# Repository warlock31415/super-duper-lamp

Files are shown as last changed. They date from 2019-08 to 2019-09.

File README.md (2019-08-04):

# super-duper-lamp
This repo contains files for building a single direction traffic control unit using discrete logic. 

The circuit uses a 555 timer to generate a 1Hz signal which increments a BCD counter. The outputs from the counter are fed into logic gates
to ensure that the correct light is turned on. The green and red lights1 thus turn on for 6 seconds individually. And the yellow light turns 
on for 4 seconds.

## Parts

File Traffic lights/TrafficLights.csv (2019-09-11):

Qty | Value | Device | Package | Parts | Description | CUI_PURCHASE_URL | DESCRIPTION | DIGI-KEY_PART_NUMBER | DIGI-KEY_PURCHASE_URL | MANUFACTURER | MANUFACTURER_PART_NUMBER | MF | MP | MPN | OC_FARNELL | OC_NEWARK | PACKAGE | POPULARITY | SPICEPREFIX | STANDARD | VALUE | VENDOR
3 | 1.33k | R-US_R1206 | R1206 | R4, R5, R6 | RESISTOR, American symbol |  |  |  |  |  |  |  |  |  |  |  |  | 19 | R
2 | 10k | R-US_0207/2V | 0207/2V | R11, R12 | RESISTOR, American symbol |  |  |  |  |  |  |  |  |  |  |  |  | 0 | R
3 | 10k | R-US_R1206 | R1206 | R1, R2, R13 | RESISTOR, American symbol |  |  |  |  |  |  |  |  |  |  |  |  | 19 | R
2 | 10uF | C-USC1206 | C1206 | C2, C3 | CAPACITOR, American symbol |  |  |  |  |  |  |  |  |  |  |  |  |  | C
5 | 1k | R-US_R1206 | R1206 | R3, R7, R8, R9, R10 | RESISTOR, American symbol |  |  |  |  |  |  |  |  |  |  |  |  | 19 | R
1 | 47uF | C-USC1206 | C1206 | C1 | CAPACITOR, American symbol |  |  |  |  |  |  |  |  |  |  |  |  |  | C
1 | CD4071BM96D14-M | CD4073BM96D14-M | D14-M | U6 |  |  |  |  |  |  | CD4073BM96 |  |  |  |  |  |  |  |  |  |  | Texas Instruments
1 | CD4073BM96D14-M | CD4073BM96D14-M | D14-M | U5 |  |  |  |  |  |  | CD4073BM96 |  |  |  |  |  |  |  |  |  |  | Texas Instruments
1 | CD4518BE | CD4518BE | N16 | U3 |  |  |  |  |  |  | CD4518BE |  |  |  |  |  |  |  |  |  |  | Texas Instruments
3 | CPC1970 | CPC1972 | 6-DIP | IC1, IC2, IC3 | Solid State Relay SPST-NO (1 Form A) 6-DIP |  |  |  |  |  | CPC1972G |  |  |  |  |  |  |  |  |  | CPC1970
1 | HEF4049B | HEF4049B | SO16 | IC5
1 | MC14081BDR2GSOIC-14_NB-M | MC14081BDR2GSOIC-14_NB-M | SOIC-14_NB-M | U4 |  |  |  |  |  |  | MC14081BDR2G |  |  |  |  |  |  |  |  |  |  | ON Semiconductor
1 | NE555 | NE555 | DIL-08 | IC4 | General purpose bipolar Timer |  |  |  |  |  |  | Arrow Electronics |  | NE555N | 1467742 | 89K1486
1 | PJ-037A | PJ-037A | CUI_PJ-037A | J2 | 2.0 mm Center Pin, 2.5 A, Right Angle, Through Hole, Dc Power Jack Connector | https://www.cui.com/product/interconnect/connectors/dc-power-connectors/jacks/pj-037a | 2.0 x 6.5 mm, 2.5 A, Horizontal, Through Hole, Dc Power Jack Connector | CP-037A-ND | https://www.digikey.com/product-detail/en/cui-inc/PJ-037A/CP-037A-ND/1644545 |  |  | CUI Inc. | PJ-037A |  |  |  | None
2 | SQ1922AEEH | SQ1922AEEH | SOT-363 | U1, U2 | Mosfet Array 2 N-Channel (Dual) 20V 850mA (Tc) 1.5W (Tc) Surface Mount SC-70-6 |  |  |  |  |  | SQ1922AEEH-T1_GE3
1 | TB002-500-04BE | TB002-500-04BE | CUI_TB002-500-04BE | J1 |  |  |  |  |  | CUI |  |  |  |  |  |  |  |  |  | Manufacturer Recommendations

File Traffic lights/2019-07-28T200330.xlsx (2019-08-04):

Index | Quantity | Part Number | Manufacturer Part Number | Description | Customer Reference | Available | Backorder | Unit Price | Extended Price USD
1 | 5 | CLA224-ND | CPC1972G | SSR RELAY SPST-NO 250MA 0-800V |  | 5 | 0 | 0.98 | 4.90
2 | 2 | 296-2076-5-ND | CD4518BE | IC BCD UP COUNTER DUAL 16-DIP |  | 2 | 0 | 0.56 | 1.12
3 | 3 | 296-31519-1-ND | CD4073BM96 | IC GATE AND 3CH 3-INP 14SOIC |  | 3 | 0 | 0.42 | 1.26
4 | 4 | MC14081BDR2GOSCT-ND | MC14081BDR2G | IC GATE AND 4CH 2-INP 14SOIC |  | 4 | 0 | 0.43 | 1.72
5 | 5 | 1727-6409-1-ND | HEF4049BT,653 | IC INVERTER 6CH 6-INP 16SO |  | 5 | 0 | 0.4 | 2.00
6 | 6 | 296-25953-1-ND | CD4071BM96 | IC GATE OR 4CH 2-INP 14SOIC |  | 6 | 0 | 0.42 | 2.52
7 | 7 | SQ1922AEEH-T1_GE3CT-ND | SQ1922AEEH-T1_GE3 | MOSFET N-CH DUAL 20V .85A SOT-36 |  | 7 | 0 | 0.52 | 3.64
8 | 1 | 377-1887-ND | PN-1320-CMB | BOX PLSTC GRAY/CLR 2.52" X 2.28" |  | 1 | 0 | 7.4 | 7.40
9 | 10 | RMCF1206FT10K0CT-ND | RMCF1206FT10K0 | RES 10K OHM 1% 1/4W 1206 |  | 10 | 0 | 0.036 | 0.36
10 | 10 | RNCP1206FTD1K00CT-ND | RNCP1206FTD1K00 | RES 1K OHM 1% 1/2W 1206 |  | 10 | 0 | 0.093 | 0.93
11 | 10 | RNCP1206FTD1K50CT-ND | RNCP1206FTD1K50 | RES 1.5K OHM 1% 1/2W 1206 |  | 10 | 0 | 0.093 | 0.93
12 | 10 | 1276-1853-1-ND | CL31F106ZPHNNNE | CAP CER 10UF 10V Y5V 1206 |  | 10 | 0 | 0.132 | 1.32
13 | 10 | 1276-3064-1-ND | CL31A476MQHNNWE | CAP CER 47UF 6.3V X5R 1206 |  | 10 | 0 | 0.336 | 3.36

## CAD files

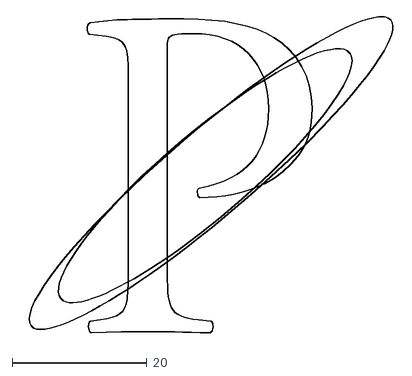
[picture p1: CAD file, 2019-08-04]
Traffic lights/drawing.dxf
56.3 x 47.4

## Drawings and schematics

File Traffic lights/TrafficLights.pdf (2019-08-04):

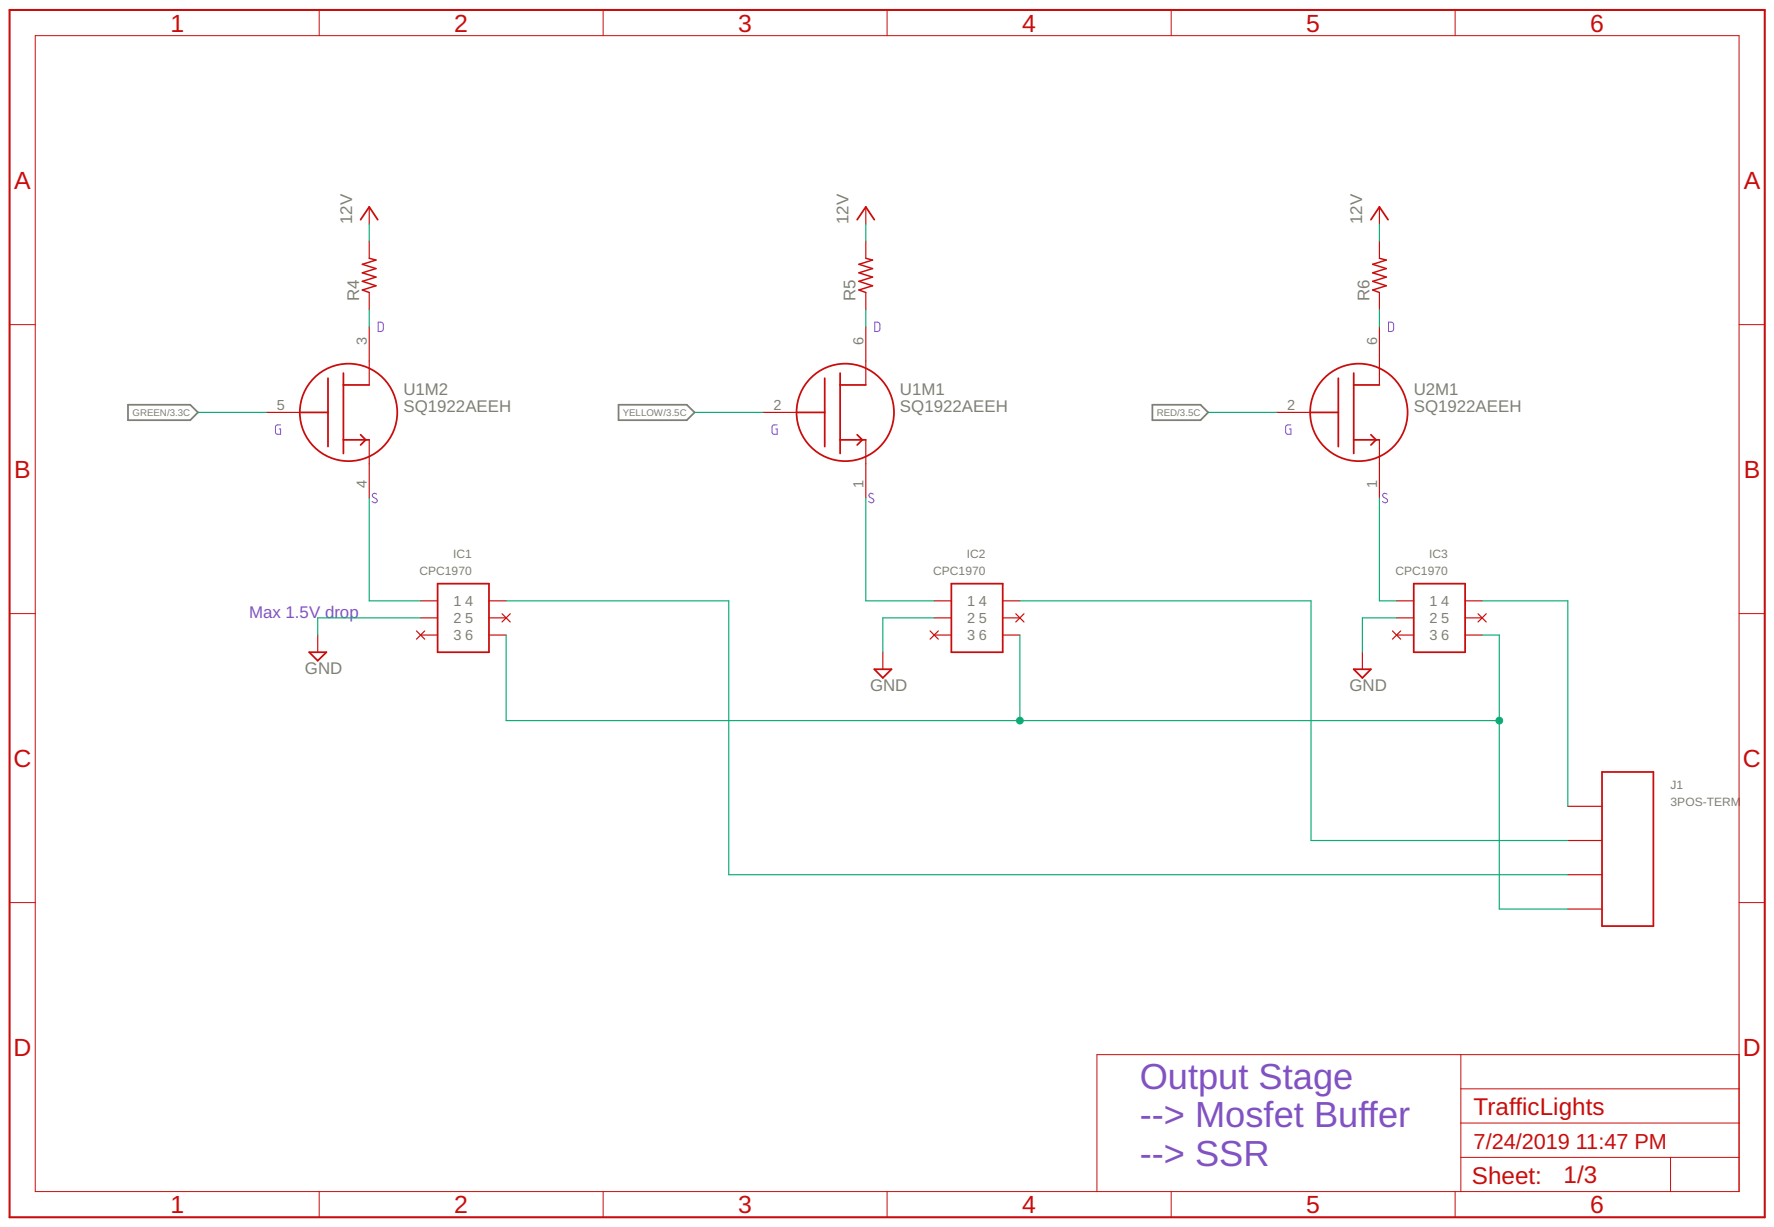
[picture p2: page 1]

Output Stage --> Mosfet Buffer --> SSR

Sheet: 1/3

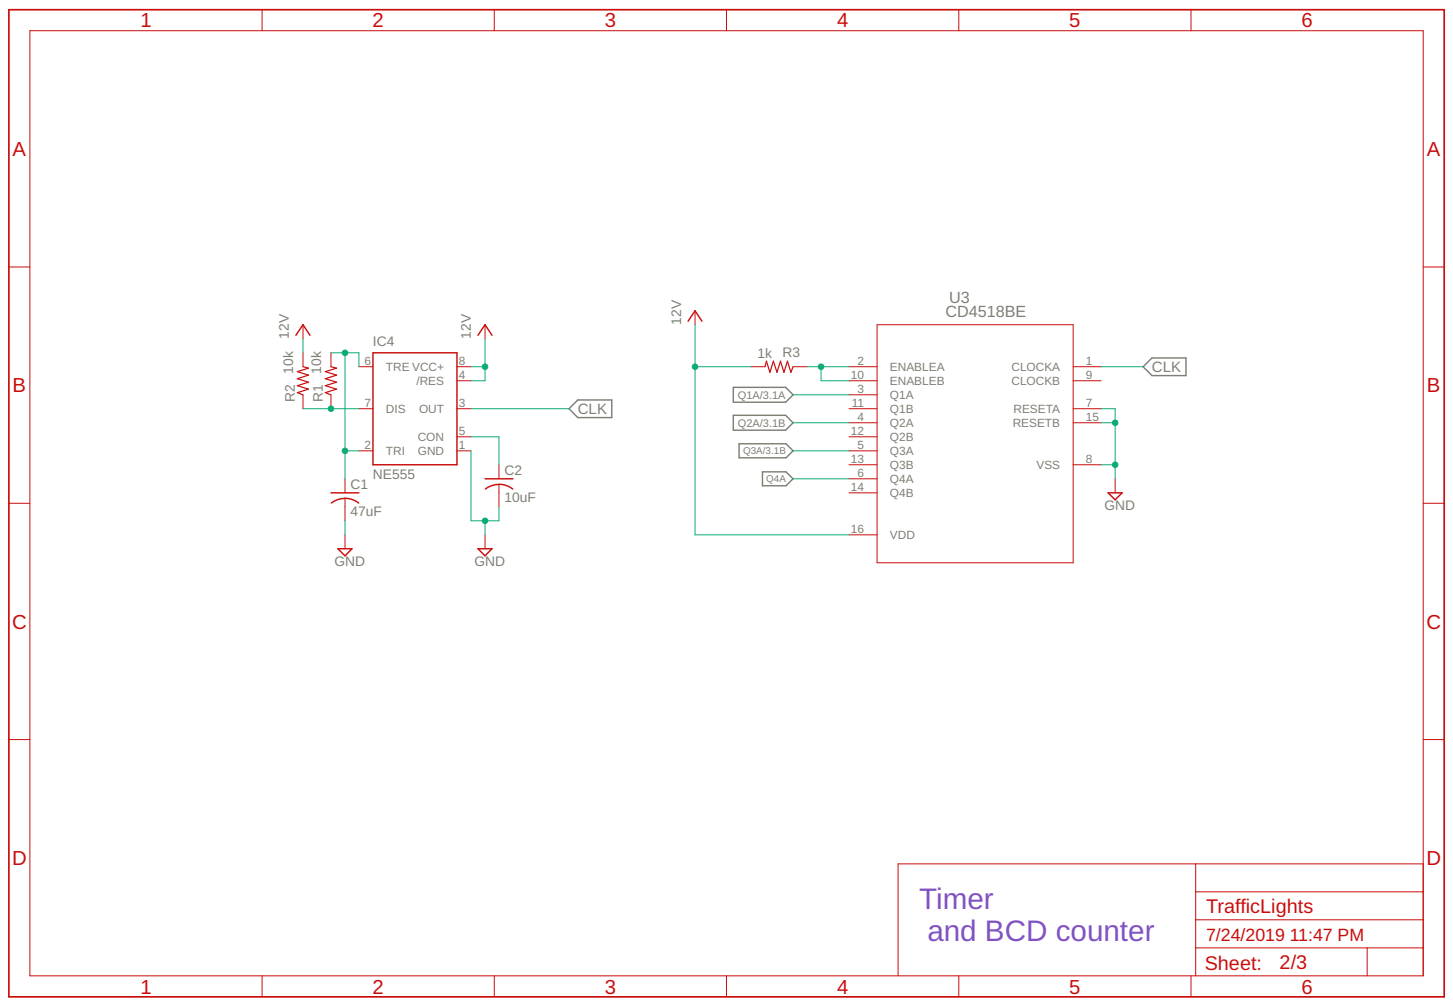
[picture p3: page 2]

Timer and BCD counter

Sheet: 2/3

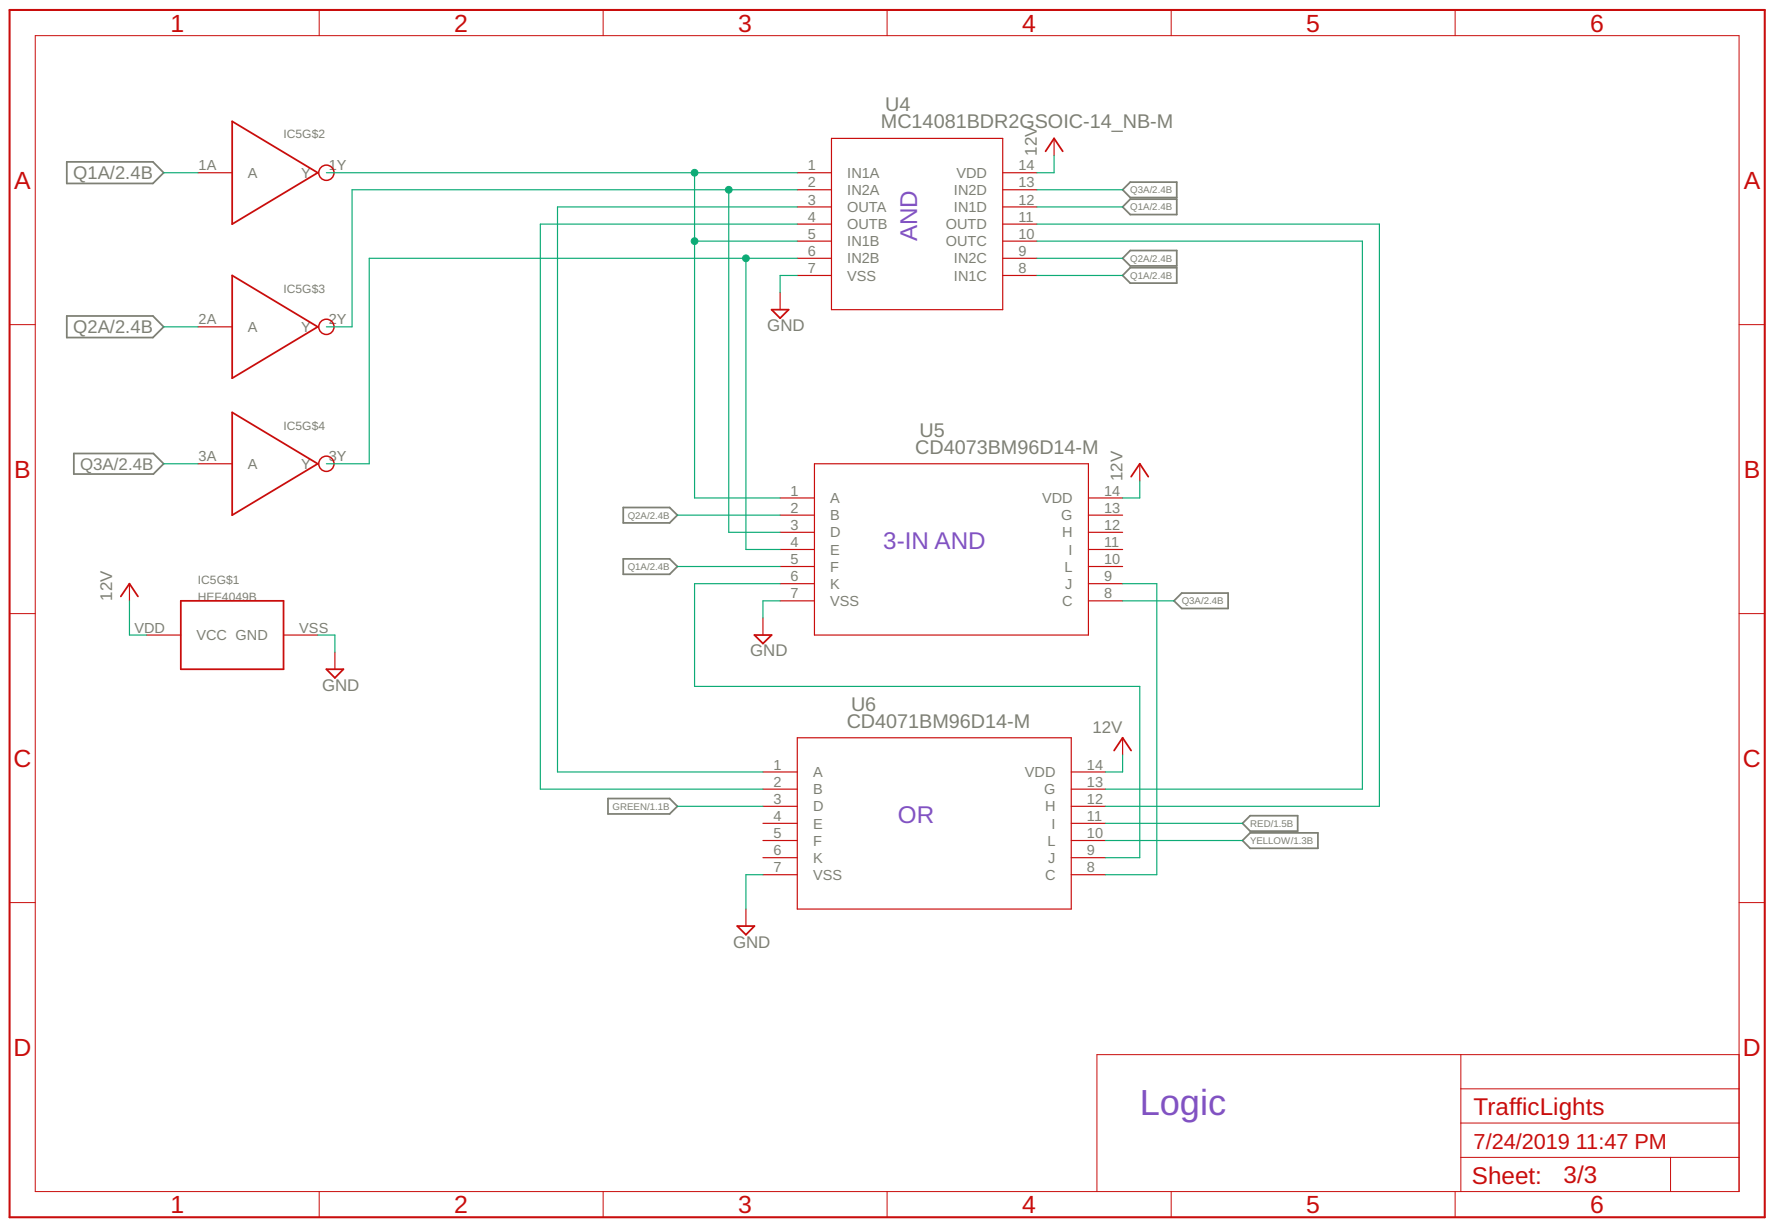
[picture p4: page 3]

Logic

Sheet: 3/3

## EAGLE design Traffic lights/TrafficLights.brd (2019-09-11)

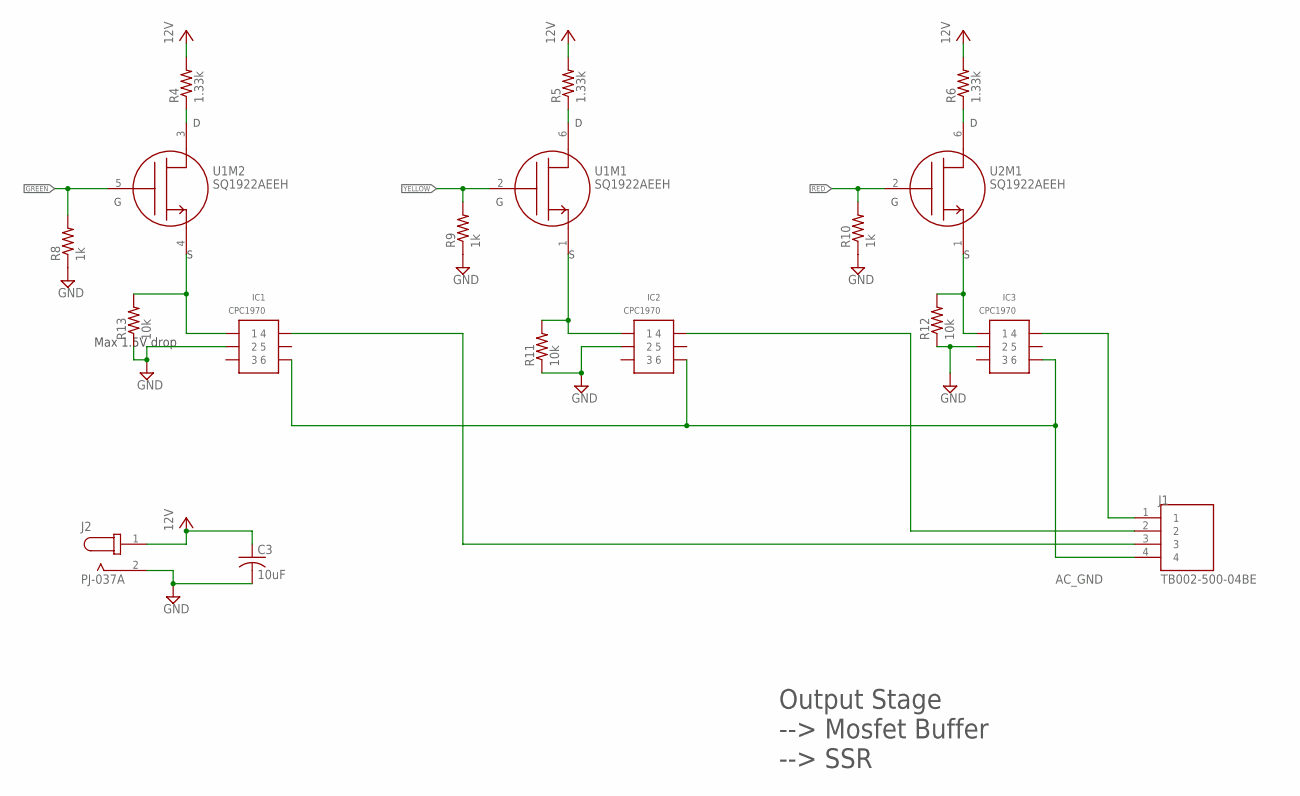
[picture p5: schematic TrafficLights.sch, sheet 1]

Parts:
C3: 10uF; C1206
IC1, IC2, IC3: CPC1970; 6-DIP
J1: TB002-500-04BE; CUI_TB002-500-04BE
J2: PJ-037A; CUI_PJ-037A
R4, R5, R6: 1.33k; R1206
R8, R9, R10: 1k; R1206
R11, R12: 10k; 0207/2V
R13: 10k; R1206
U1, U2: SQ1922AEEH; SOT-363

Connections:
AC_GND: IC1.P$6 (6), IC2.P$6 (6), IC3.P$6 (6), J1.4
GND: C3.2, IC1.P$2 (2), IC2.P$2 (2), IC3.P$2 (2), J2.2, R8.1, R9.1, R10.1, R11.1, R12.1, R13.1; also elsewhere on the board
GREEN: R8.2, U1.5 (G); also elsewhere on the board
unnamed: IC1.P$1 (1), R13.2, U1.4 (S)
unnamed: IC2.P$1 (1), R11.2, U1.1 (S)
unnamed: IC3.P$1 (1), R12.2, U2.1 (S)
unnamed: R4.1, U1.3 (D)
unnamed: R5.1, U1.6 (D)
unnamed: R6.1, U2.6 (D)
unnamed: IC2.P$4 (4), J1.2
unnamed: IC3.P$4 (4), J1.1
RED: R10.2, U2.2 (G); also elsewhere on the board
VAC: IC1.P$4 (4), J1.3
VCC: C3.1, J2.1, R4.2, R5.2, R6.2; also elsewhere on the board
YELLOW: R9.2, U1.2 (G); also elsewhere on the board

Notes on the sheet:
Max 1.5V drop
Output Stage --> Mosfet Buffer --> SSR

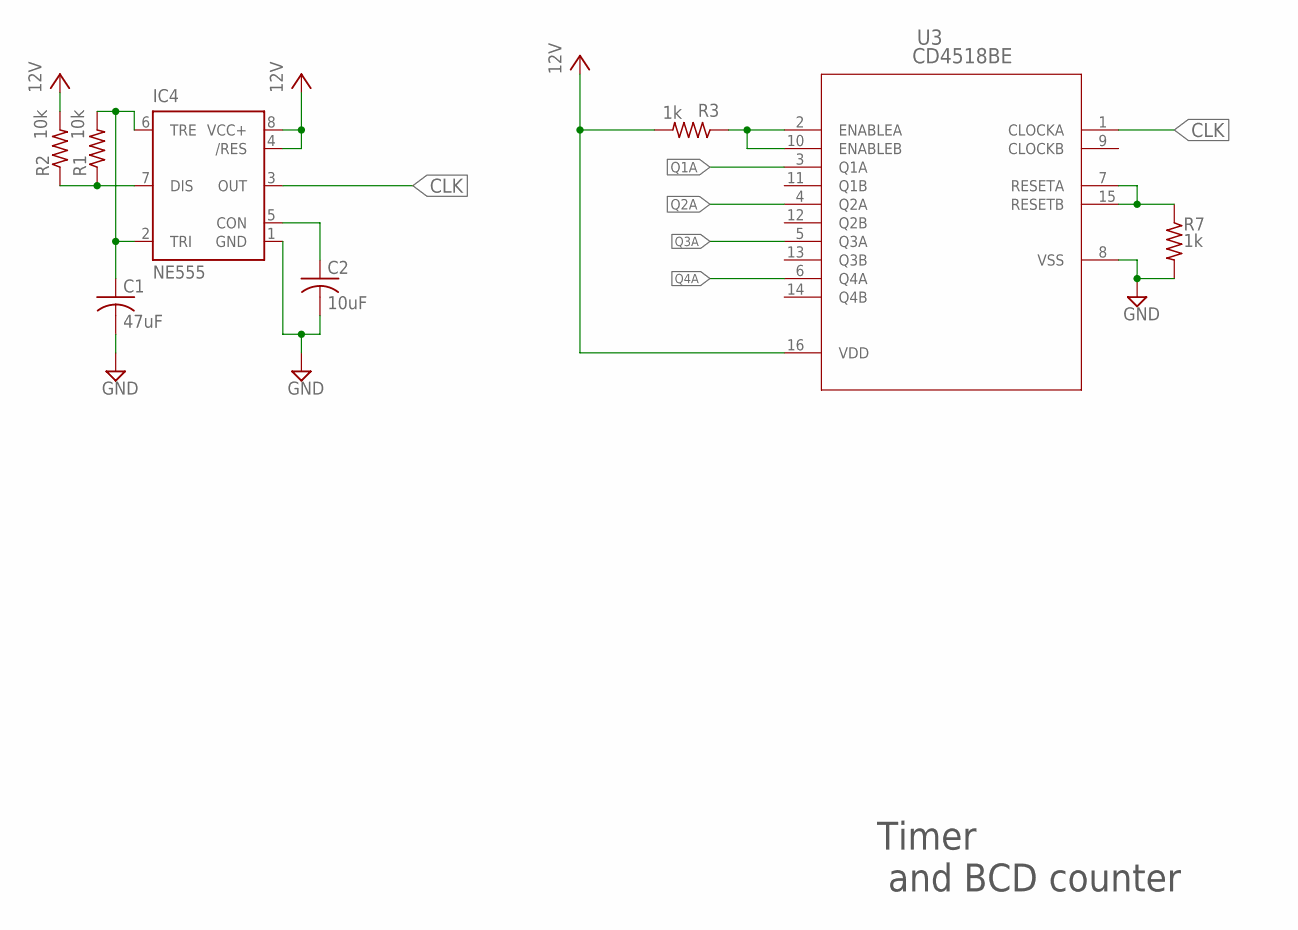
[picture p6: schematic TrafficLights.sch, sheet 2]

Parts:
C1: 47uF; C1206
C2: 10uF; C1206
IC4: NE555; DIL-08
R1, R2: 10k; R1206
R3, R7: 1k; R1206
U3: CD4518BE; N16

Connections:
CLK: IC4.3 (OUT), U3.1 (CLOCKA)
GND: C1.2, C2.2, IC4.1 (GND), R7.2, U3.8 (VSS); also elsewhere on the board
unnamed: IC4.7 (DIS), R1.1, R2.1
unnamed: C1.1, IC4.2 (TRI), IC4.6 (TRE), R1.2
unnamed: C2.1, IC4.5 (CON)
unnamed: R3.1, U3.2 (ENABLEA), U3.10 (ENABLEB)
unnamed: R7.1, U3.7 (RESETA), U3.15 (RESETB)
Q1A: U3.3 (Q1A)
Q2A: U3.4 (Q2A); also elsewhere on the board
Q3A: U3.5 (Q3A); also elsewhere on the board
Q4A: U3.6 (Q4A); also elsewhere on the board
VCC: IC4.4 (/RES), IC4.8 (VCC+), R2.2, R3.2, U3.16 (VDD); also elsewhere on the board

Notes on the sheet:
Timer and BCD counter

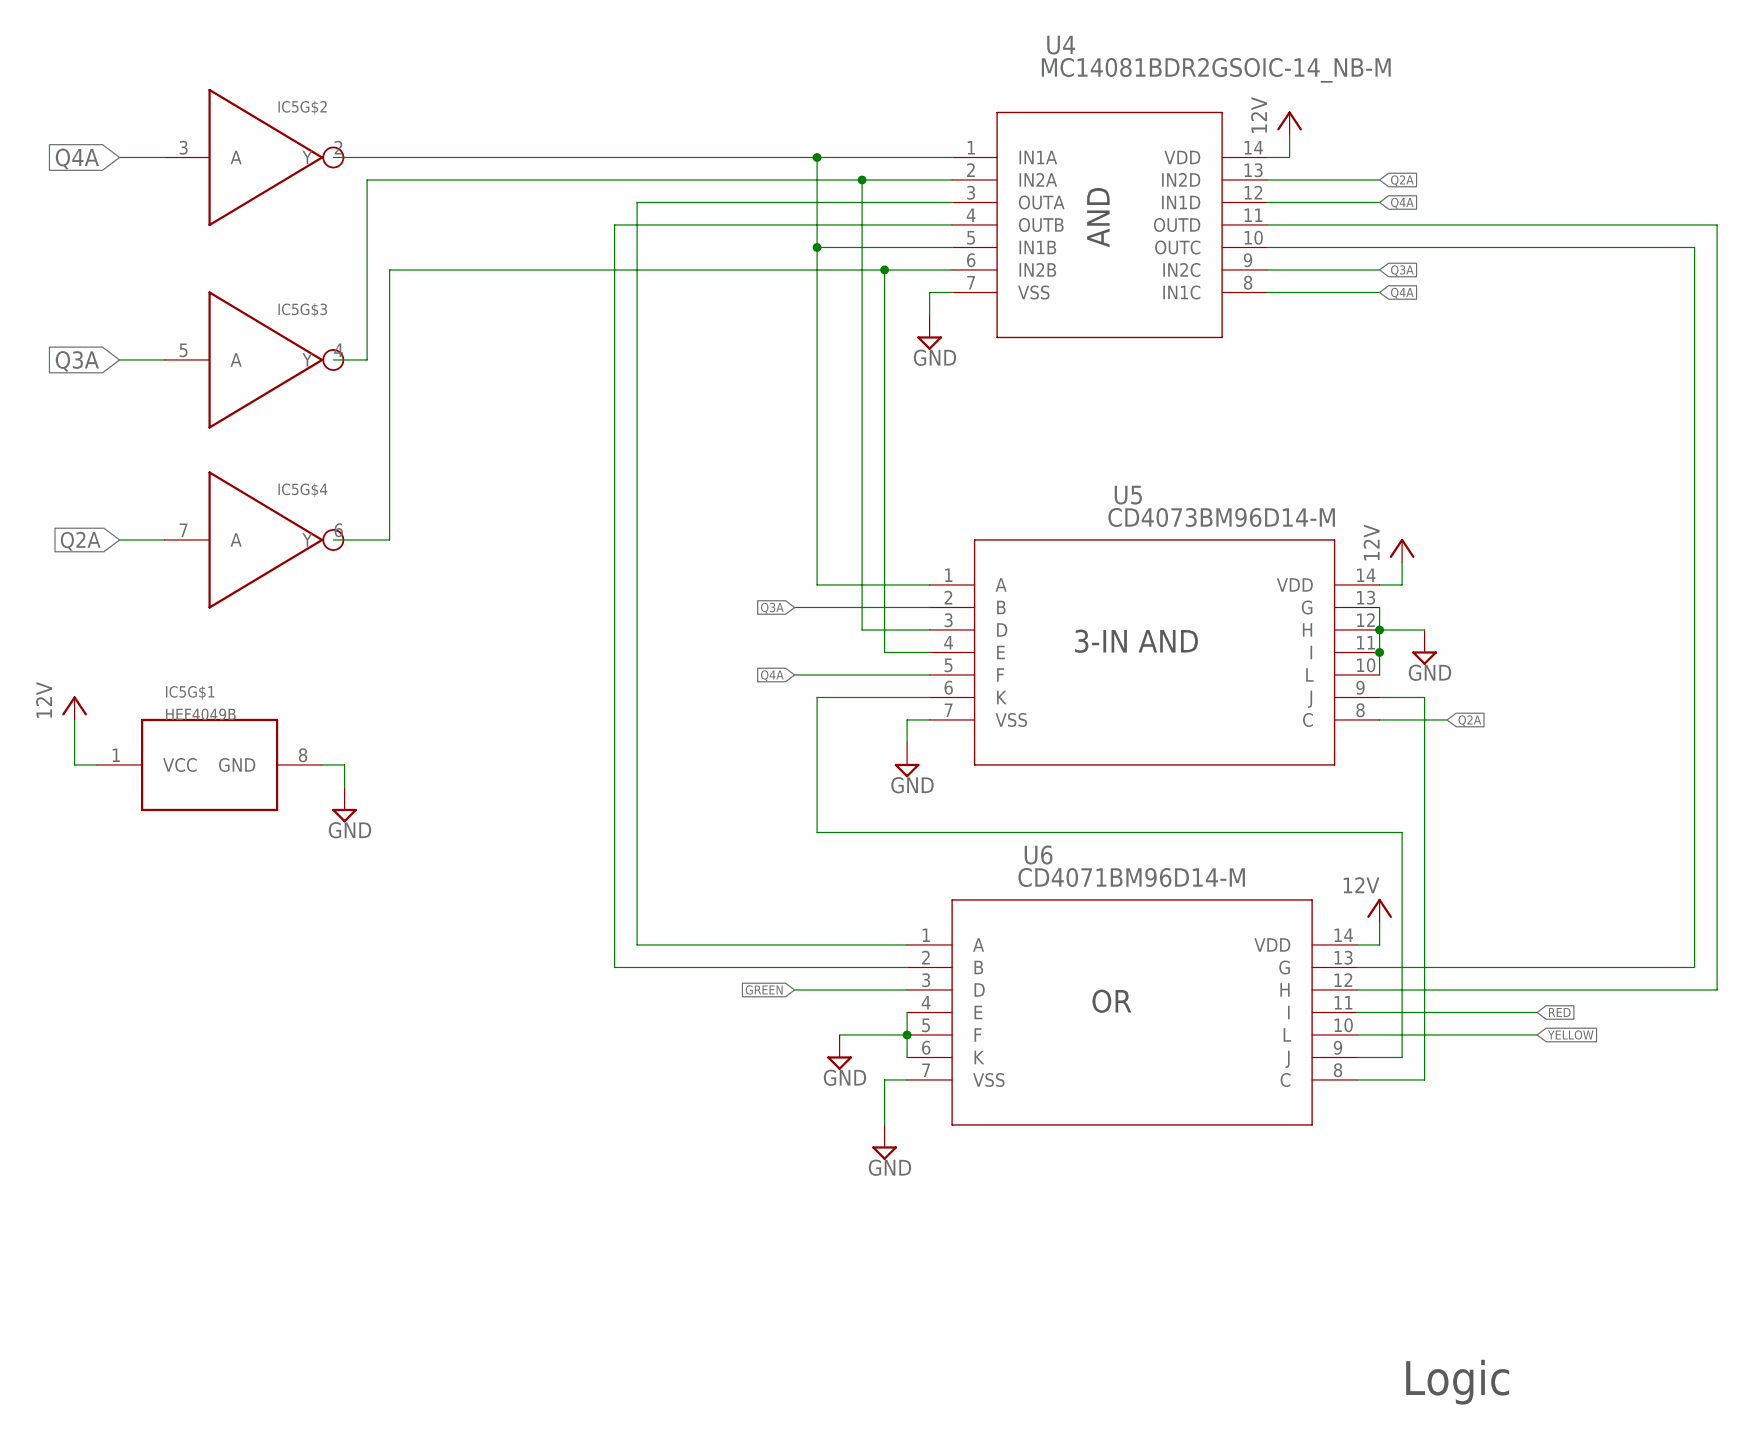
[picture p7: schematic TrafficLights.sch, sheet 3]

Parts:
IC5: HEF4049B; SO16
U4: MC14081BDR2GSOIC-14_NB-M; SOIC-14_NB-M
U5: CD4073BM96D14-M; D14-M
U6: CD4071BM96D14-M; D14-M

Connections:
GND: IC5.8 (GND), U4.7 (VSS), U5.7 (VSS), U5.10 (L), U5.11 (I), U5.12 (H), U5.13 (G), U6.4 (E), U6.5 (F), U6.6 (K), U6.7 (VSS); also elsewhere on the board
GREEN: U6.3 (D); also elsewhere on the board
unnamed: IC5.2 (Y), U4.1 (IN1A), U4.5 (IN1B), U5.1 (A)
unnamed: IC5.4 (Y), U4.2 (IN2A), U5.3 (D)
unnamed: IC5.6 (Y), U4.6 (IN2B), U5.4 (E)
unnamed: U4.3 (OUTA), U6.1 (A)
unnamed: U4.4 (OUTB), U6.2 (B)
unnamed: U4.10 (OUTC), U6.13 (G)
unnamed: U4.11 (OUTD), U6.12 (H)
unnamed: U5.9 (J), U6.8 (C)
unnamed: U5.6 (K), U6.9 (J)
Q2A: IC5.7 (A), U4.13 (IN2D), U5.8 (C); also elsewhere on the board
Q3A: IC5.5 (A), U4.9 (IN2C), U5.2 (B); also elsewhere on the board
Q4A: IC5.3 (A), U4.8 (IN1C), U4.12 (IN1D), U5.5 (F); also elsewhere on the board
RED: U6.11 (I); also elsewhere on the board
VCC: IC5.1 (VCC), U4.14 (VDD), U5.14 (VDD), U6.14 (VDD); also elsewhere on the board
YELLOW: U6.10 (L); also elsewhere on the board

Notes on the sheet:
Logic
AND
3-IN AND

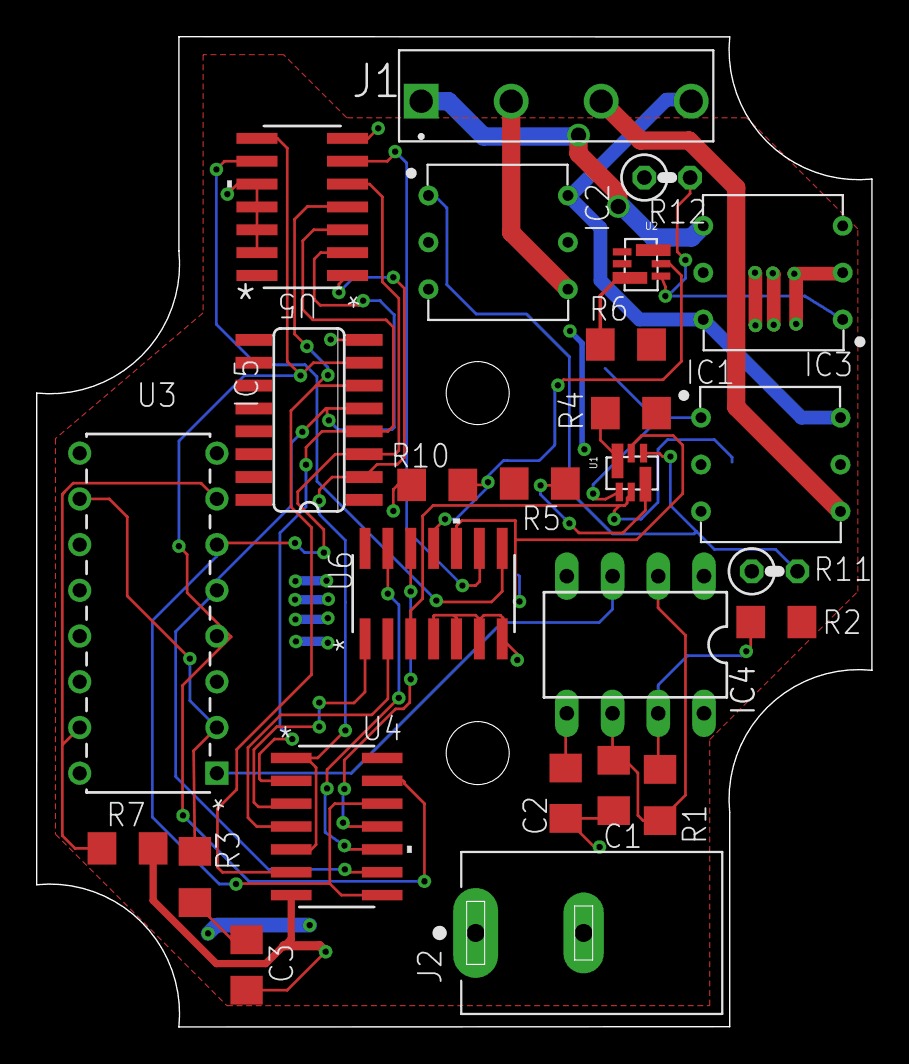
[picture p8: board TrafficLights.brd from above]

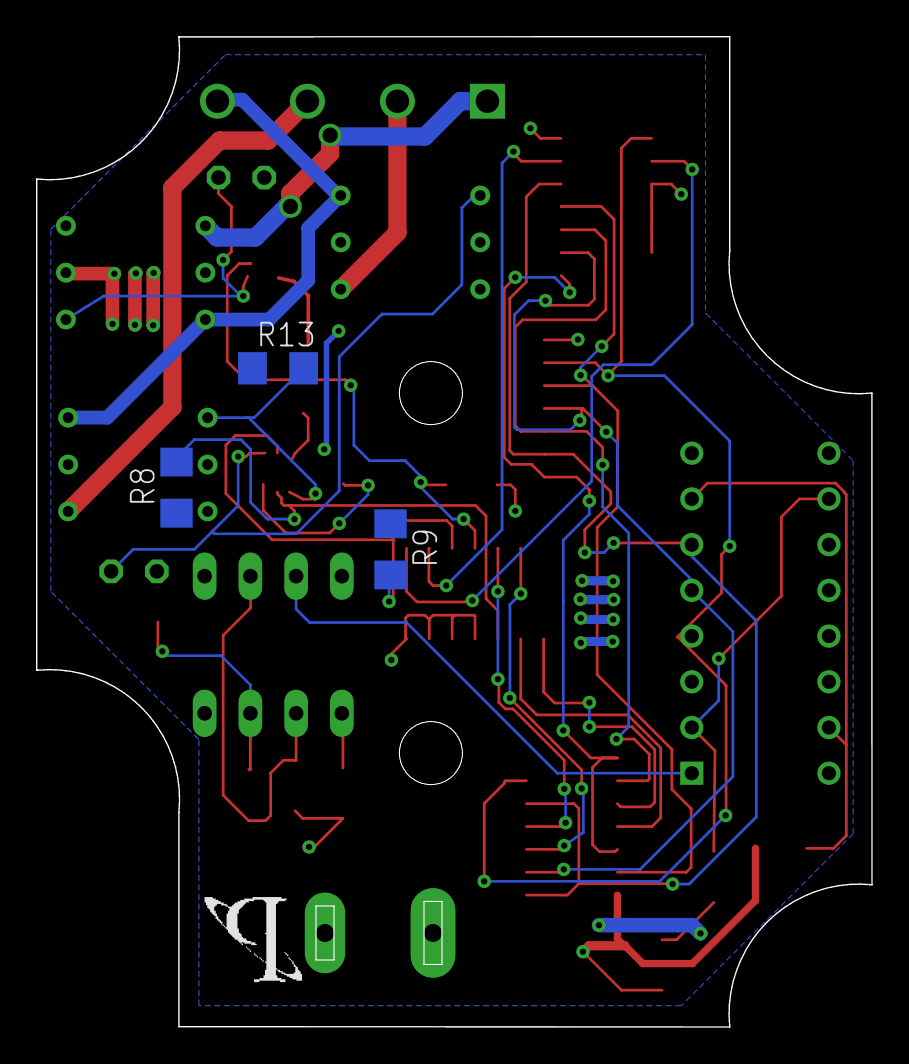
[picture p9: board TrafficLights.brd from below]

Board: 2 copper layers, 46.4 x 55.0 mm, 29 parts (3 on the bottom side), 33 nets.

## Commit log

2019-08-24 Added pull down resistors on SSRs, fixed inverter footprint.
2019-09-11 Fixed stuff
    [TrafficLights.brd, TrafficLights.csv, TrafficLights.sch]
